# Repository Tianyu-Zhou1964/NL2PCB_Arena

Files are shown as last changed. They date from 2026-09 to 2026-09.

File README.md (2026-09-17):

# NL2PCB-Arena

让任意"基模 + harness"组合在同一个考场做 NL2PCB-Bench 的题，并把结果按统一口径汇总。
考场、agent 适配、轨迹、并发由 [Harbor](https://github.com/harbor-framework/harbor) 提供；本仓库只做三件事：

1. **题包**：`dataset/<task>/` 是一个 Harbor 任务。评测侧的 `bench/`（NL2PCB-Bench 任务目录：完整 `config.toml`、`cases/`）只进 verifier 镜像；发给 agent 的 `environment/`（题面、元件、工艺、骨架、公开自检配置）由 `nl2pcb-arena export` 生成。
2. **判卷**：`verifier/grader.py` 在独立、断网的 verifier 容器里跑完整的 `nl2pcb check`，写 `reward.json`（0/1）与 `grading.json`（逐规则状态、四类结果状态）。
3. **汇总**：`nl2pcb-arena report` 把 Harbor 的 job 结果按 任务 × harness × 模型 汇总成 pass@1、pass^k、规则级通过率、成本与轮数；基础设施故障不进能力分母。

## 快速开始（服务器，Docker 可用）

```sh
uv tool install harbor                                   # 0.23
scripts/sync_vendor.sh ../NL2PCB-Bench ../pcblite        # 依赖快照 + commit 记录
BASE_IMAGE=docker.m.daocloud.io/library/ubuntu:24.04 APT_MIRROR=mirrors.tuna.tsinghua.edu.cn \
    images/build.sh dev                                  # agent 镜像 → 导出题包 → verifier 镜像
scripts/server/prepare_harbor_sidecar.sh                 # 拉不到 Docker Hub 的机器：预构建 Harbor 的断网 sidecar
harbor run -p dataset/mini-led -a oracle                 # 参考答案应得 reward 1
harbor run -p dataset/mini-led -a nop                    # 什么都不做应得 0
harbor run -p dataset -a claude-code -m anthropic/claude-sonnet-5 -k 3 -n 4   # 真跑（花钱）
uv run nl2pcb-arena report jobs/<job>                    # 汇总
harbor add dataset/<新题> --to dataset && (cd dataset && harbor sync)   # 新题入清单、刷新 digest
```

## 考场里有什么

`kicad-cli`（KiCad 10.0.6，PPA 锁版）、`python3` + `pcbnew`、`ngspice`、`pcblite`（查询/编辑 `.kicad_pcb` 的命令行）、`nl2pcb check /task /workspace/answer.kicad_pcb`（公开规则自检）。没有 KiCad 标准库，封装只来自题包。agent 阶段可联网（模型端点需要），verifier 阶段断网。

## 题目

| 任务 | 层 | 起手板 | 公开规则 | 隐藏规则 |
|---|---|---|---|---|
| `mini-led` | L4 整板 | 骨架 | `pcb.drc`、`layout.fixed` | `electrical.led.current` |
| `mini-led-select` | L1 选型 | 骨架 | `layout.fixed`（`pcb.drc` 关：不要求布线） | `electrical.led.current` |
| `mini-led-repair-open` | L3 修复 | 开路板（缺一段走线，公开 DRC 报未连接） | `pcb.drc`、`layout.fixed` | `electrical.led.current` |
| `mini-led-repair-overcurrent` | L3 复核 | 47 Ω 板（DRC 干净，LED 约 62 mA） | `pcb.drc`、`layout.fixed` | `electrical.led.current` |

**通过不代表什么**（每题 `task.toml` 的 `not_implied` 也写了）：
L1 选型通过不代表会布线；L3 修复通过不代表能从零设计；L4 整板通过不代表可量产、可靠、EMC 合规；所有题的通过都只针对已配置的规则，不覆盖题面里没有对应规则的要求（工艺、焊接方式），也不代表真实焊接点亮过。

## 结果状态

| 状态 | 判定 |
|---|---|
| `passed` | 完整规则全部通过（`nl2pcb check` 退出 0） |
| `capability_failed` | 其余：答案缺失、解析失败、任一规则 fail/inconclusive |
| `agent_reported_blocker` | agent 写了 `/workspace/BLOCKER.md` |
| `infrastructure_failure` | 评分器自身失败（配置错误、超时、参考板也无法检查）、Harbor 报环境/agent 安装异常 |

`grading.json` 的 `network.isolated` 记录判卷容器是否真的断网（Harbor 的出口控制在内核探针失败时会静默关闭）；汇总报表会把 `false` 的 trial 单列出来。

`official_score_available = false`：本地 Docker 运行、agent 可联网、未经第三方盲测。正式对比要固定镜像 digest、题包 digest（`dataset.toml`）、Harbor 版本、重复次数与网络策略。

## 目录

```
dataset/<task>/          Harbor 任务：task.toml、instruction.md、bench/（评测侧）、environment/（生成）、solution/
images/agent/Dockerfile  共享 agent 镜像
images/verifier.Dockerfile  FROM agent + grader + dataset/*/bench
verifier/grader.py       判卷
src/nl2pcb_arena/        export（题包导出）、report（汇总）
vendor/                  NL2PCB-Bench、pcblite 快照（不提交，VERSIONS.json 记 commit）
docs/PLAN.md             方案与计划书
```

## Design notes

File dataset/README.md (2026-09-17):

# nl2pcb/nl2pcb-arena

Harbor 数据集清单 `dataset.toml` 由 `harbor dataset init` 生成，新题用 `harbor add dataset/<id> --to dataset` 加入，`harbor sync` 刷新 digest；每个子目录是一道 Harbor 任务。
题目形态、公开/隐藏规则与"通过不代表什么"见仓库根 `README.md` 与 `docs/PLAN.md`。

| 任务 | 层 | 起手板 | 公开规则 | 隐藏规则 |
|---|---|---|---|---|
| `mini-led` | L4 整板 | 骨架 | `pcb.drc`、`layout.fixed` | `electrical.led.current` |
| `mini-led-select` | L1 选型 | 骨架 | `layout.fixed`（`pcb.drc` 关：不要求布线） | `electrical.led.current` |
| `mini-led-repair-open` | L3 修复 | 开路板（缺一段走线） | `pcb.drc`、`layout.fixed` | `electrical.led.current` |
| `mini-led-repair-overcurrent` | L3 复核 | 47 Ω 板（DRC 干净但 LED 约 62 mA） | `pcb.drc`、`layout.fixed` | `electrical.led.current` |

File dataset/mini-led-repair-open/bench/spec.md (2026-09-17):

# 电源指示板（修复）

**目标**：从零设计一块用于普通桌面设备的5V单路LED电源指示PCB小板。

**功能**：+5 V （允许4.75–5.25V，外部电源限流20mA）经 2 脚连接器 J1 进板（1 脚正、2 脚回流），点亮一颗指示灯 D2。

**机械规格**：板框与 J1 的位置、方向已在 `assets/skeleton.kicad_pcb` 固定，不得修改。

**制造规格**：嘉立创普通 FR4 双层板、1 oz 外层铜、绿色阻焊、无铅喷锡、铣边，参数见 `assets/process/jlc_fr4_2l_1oz.toml`。贴片元件回流焊，J1 手焊。

**元件**：只能从 `assets/parts/` 选，清单见 `assets/parts/list.md`。位号 J1、D2 固定，其余自定。footprint 的 `Value` 写清单里的元件 id。

| 位号 | 元件 id | 说明 |
|---|---|---|
| J1 | `conn_2p_2mm` | 电源输入，1 脚 +5 V，2 脚回流 |
| D2 | `led_0805_red` | 指示灯 |

**起手板**：`answer.kicad_pcb` 的初始内容是一块已有的设计，它没有通过公开自检。请找出问题并修复后交付，改动尽量小；板框与 J1 不得修改。

**输出**：输出 `answer.kicad_pcb`，格式见 `assets/mini_kicad.md`。

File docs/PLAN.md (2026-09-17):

# NL2PCB-Arena 方案与计划书

2026-09-17 定稿（同日两版：先按自写 runner 写了一版；看过 Harbor 与 EDA-bench 后改为本版）。开发机：`zhou` 服务器 `~/zhoutianyu/NL2PCB-Arena`。

## 0. 一句话

NL2PCB-Bench 回答"这块板对不对"；NL2PCB-Arena 让任意 **基模 + harness** 组合在同一个考场做同一批题，并按统一口径汇总。Arena **不写 runner、不写 agent**：考场（Docker）、agent 适配（Claude Code / Codex / terminus-2 等 40 多个）、ATIF 轨迹、token 与成本记账、并发、重试、独立 verifier 环境全部由 [Harbor](https://github.com/harbor-framework/harbor)（Terminal-Bench 2.0 的官方 harness，0.23）提供。Arena 只做三件事：**题包、判卷、汇总**。同物种的 EDA-bench 就是这样建在 Harbor 上的，我们的结果口径可以和它直接对照。

## 1. 已定决策

| 编号 | 决策 | 结论 |
|---|---|---|
| D1 工具 | 考场提供什么 | 只提供命令行：`kicad-cli`、`pcblite`、公开版 `nl2pcb check`、`python3`（含 pcbnew）、`ngspice`。只要 harness 能执行 shell 就能参赛 |
| D2 自测 | agent 能否自测 | 能。容器内 `nl2pcb check /task /workspace/answer.kicad_pcb` 只跑**公开规则**；评分跑**全部规则**（含隐藏） |
| D3 隔离 | 隔离到什么程度 | Docker。评测侧文件只进 verifier 镜像；Harbor `environment_mode = "separate"` 在**全新、断网**的 verifier 容器里判卷，只有 `artifacts` 声明的 `/workspace` 被搬过去 |
| D4 框架 | 自写 runner 还是用现成 | **用 Harbor**。Arena 仓库 = 一个 Harbor 数据集 + 两个镜像 + 判卷脚本 + 汇总工具 |
| D5 仓库 | 代码放哪 | 新仓库 `NL2PCB-Arena`。Bench 与 pcblite 作为版本锁定的依赖（`scripts/sync_vendor.sh` 复制快照，commit 记进 `vendor/VERSIONS.json`），不改它们的代码 |
| D6 开发机 | 在哪开发 | `zhou`（Ubuntu 22.04 x86_64，256 核 / 377G / 1.5T 空闲 / Docker 28.3 + Compose v2.38）。本机只保留临时编辑镜像并 rsync |

## 2. 调查结论（事实，带出处）

### 2.1 NL2PCB-Bench（判卷器）

- 唯一入口 `nl2pcb check <task_dir> <answer.kicad_pcb> [--json]`，退出码 0 通过 / 1 有 error 级未通过 / 2 配置不合法 / 101 工具崩溃（`src/nl2pcb/cli.py:1-7`）。`--json` 每条 `diagnostic`、`report` 一行，末行 `run`。
- 任务目录可在仓库外；配置里**没有"公开/隐藏规则"概念**，规则调用的键按函数签名严格校验（`check/calls.py:130`）。公开/隐藏由 Arena 派生两份 config。
- 三条后端路径都要进容器：`kicad-cli`、KiCad 的 pcbnew Python（版本须 `10.0.*`，`worker.py:28`）、`ngspice`。
- 退出 101 不一定是环境坏了：损坏的答案文件也会让 `kicad-cli pcb export pos` 非零退出、`layout.fixed` 报 `crashed`。判卷时要拿参考板复核一次再定性（§5）。
- `spec/mini_kicad.md` 仍是占位，`lang/` 未写；题面改为"输出 KiCad 10 原生 `.kicad_pcb`"。

### 2.2 pcblite（agent 的改板工具）

- 用**本体仓库**（`Tianyu-Zhou1964/pcblite`，HEAD `feefd87`）的 `pcblite/` 包：纯标准库、11 个 .py、不 import pcbnew；`kicad-cli` 只在 `--refill`/`--check`/`verify`/老文件升级时用。没有 pyproject，容器里包一层 `/usr/local/bin/pcblite`。
- 31 个子命令：`open/export`、10 个查询、18 个编辑操作、`apply` 批量原子。编辑失败退出码 2 且不落盘。
- 交接包里的 9 个 JSON 工具是"从空板建板"协议（`agent_state.design()` 对存量板抛 `ARCHIVE_NOT_ALLOWED`，且依赖 pcbnew），**不采用**。
- **待验证风险**：`open → export → nl2pcb check` 在 09-14 跑通过，但早于 Bench 合入"封装库一致性 DRC"（PR #13）。verifier 镜像构建自检只验参考板；pcblite 往返要单独测（§8 P3）。

### 2.3 Harbor（考场与 runner）

- 任务 = 目录：`task.toml`（`schema_version = "1.4"`）+ `instruction.md` + `environment/`（agent 镜像构建上下文）+ `solution/solve.sh`（oracle）+ 可选 `tests/`。`harbor run -p <目录>` 直接跑本地任务或任务集合，无需发布。
- **separate verifier**：`[verifier] environment_mode = "separate"` + `[verifier.environment] docker_image = ...`；Harbor 先停 agent 容器，把 `artifacts` 声明的路径搬进新容器（原路径还原），`/logs/verifier` 先清空再跑 `/tests/test.sh`。**`tests/` 目录在 separate 模式下永不上传**，`test.sh` 必须烘进 verifier 镜像（`trial.py:894` `skip_tests_upload=True`）。
- reward：`/logs/verifier/reward.json`（优先）或 `reward.txt`。**pass@k 只在 reward 恰好一个键且值 ∈ {0,1} 时计算**（`utils/pass_at_k.py:44-51`）。
- agent 超时（`AgentTimeoutError`）或非零退出**不会跳过验证**：超时那一刻的工作区照常评分（`single_step.py:75-87`）；环境起不来 / agent 装不上则没有 `verifier_result`。
- 每个 trial 都在容器里装一次 agent CLI（claude-code 走 `bootstrap.sh`，codex 走 nvm + npm），默认安装超时 360 s；但 `install()` 看到 `command -v claude/codex` 成功就跳过 → **agent 镜像预装 node 22 + 两个 CLI**。
- claude-code 以 root 跑时 Harbor 自动 `IS_SANDBOX=1` + `--permission-mode=bypassPermissions`；`[agent].user` 可指定非 root。
- 模型与端点：claude-code 用 `-m <model>` + `--ae ANTHROPIC_API_KEY/ANTHROPIC_BASE_URL`（有自定义端点时模型名原样透传）；codex 用 `-m <model>` + `--ae OPENAI_API_KEY/OPENAI_BASE_URL`（Harbor 写进 `config.toml` 的 `openai_base_url`）；terminus-2（Harbor 自带的最薄 agent，LiteLLM）用 `-m openai/<model> --ak api_base=...`，密钥从**运行 harbor 的宿主环境**读。
- 产物：`jobs/<job>/<trial>/{result.json, agent/trajectory.json, agent/<原生日志>, verifier/{reward.json,test-stdout.txt,…}, artifacts/<声明路径>}`。`result.json` 有 `agent_info{name,version,model_info}`、`agent_result{n_input_tokens,n_cache_tokens,n_output_tokens,cost_usd}`、`verifier_result.rewards`、`exception_info.exception_type`、各阶段计时。内置统计给 mean reward 与 pass@k。
- 网络：`no-network` 不是 `--network none`，而是让容器共用一个 egress sidecar（基础镜像 `gogost/gost`，按内容哈希命名为 `harbor-prebuilt:harbor-docker-egress-control-sidecar--<hash>`）的网络命名空间，由它做 nftables 拦截。Harbor 会先跑 `alpine:3.23.4` 探针测内核，探针失败就**静默降级为 public**；sidecar 基础镜像要从 Docker Hub 拉，拉不到则整个 verifier 阶段报 `RuntimeError`（zhou 上已遇到：两个镜像站都不提供 gost）。对策：`scripts/server/prepare_harbor_sidecar.sh` 用 Harbor 自己的哈希算法算出镜像名、从可用镜像站按同一 digest 拉 gost 后预构建同名镜像（Harbor 见本地已有即复用）；`grader.py` 在判卷容器里实测 DNS 与 HTTP 出网（断网是透明代理，TCP 握手总成功，必须到应用层）并写进 `grading.json.network`，汇总报表把 `isolated=false` 的 trial 单列。
- 陷阱：`harbor run -o` 是 `--jobs-dir`；`-a terminus`/`terminus-1` 不可用，只有 `terminus-2`；多维 reward 文件名是 `reward.json`（模板注释里的 `rewards.json` 是错的）。

### 2.4 EDA-bench（同物种模板）

- 35 个真实开源硬件的重建任务，Harbor 0.19；**一个共享 agent 镜像 + 一个 `FROM agent` 的 verifier 镜像**，verifier 镜像里烘焙 gold、契约、评分代码与 `/tests/test.sh`，任务靠 `[verifier].env` 的 `EDA_BENCH_TASK_ID` 选择；agent 镜像构建上下文只有一个 Dockerfile 目录，物理上放不进 gold。
- `artifacts = ["/workspace/final_project"]` 单向搬运；verifier `no-network`；`grader.py` 写 `reward.json`（数值）+ `grading.json`（全部）+ `work/`。
- 值得抄：verifier `FROM` agent 保证判卷与自检用同一套二进制；相对 gold 的 DRC/ERC 打分吸收 KiCad 版本噪声；诊断项权重 0；DATA_CARD 里逐条写"高分不代表什么"。
- 不抄：全程 root、无 locale、不钉 KiCad 版本、可变镜像 tag、`metric.py` 按位置绑难度、agent 阶段开公网且 gold 公开可搜（他们自己承认）。

### 2.5 容器与服务器

- KiCad 官方镜像 `kicad/kicad:10.0` 只有 amd64；PPA `ppa:kicad/kicad-10.0-releases` 对 Ubuntu 24.04 有 amd64 与 arm64 的 `10.0.6~ubuntu24.04.1`。选 **`ubuntu:24.04` + PPA 锁版**，探针镜像已在服务器构建通过（kicad-cli 10.0.6、pcbnew 10.0.6、ngspice 42、Python 3.12.3，1.1 GB，3 分钟）。
- 服务器网络：Docker Hub 直连超时，`docker.m.daocloud.io` 可用；Ubuntu 源用清华 **http** 镜像（装 ca-certificates 前 https 不可用，已踩坑）；PPA、npm、nodejs.org 可达；GitHub 慢（构建期不 clone，改本地拷贝）；pypi 走清华。
- 本机 Mac 不用于开发：colima VM 已删；`brew` 装的 `colima`、`docker` 两个小包保留，可 `brew uninstall colima docker`。

### 2.6 从 Aspen-Agent 借的机制（只借机制）

| 借 | 落在哪 |
|---|---|
| 评分器只吃一个目录、可离线重跑、全部重算 | `harbor job regrade` + `verifier/grader.py`（separate 模式支持不重跑 agent 只重评） |
| 缺测量 = 失败，绝不视作 0 | 答案缺失/解析失败 = `capability_failed`；评分器崩溃 = `infrastructure_failure`；reward.json 一定落盘 |
| 状态分类，infra 优先级最高、不进能力分母；双分母 | `grading.json.status` + `nl2pcb-arena report`：`planned / scored / passed`，infra 与 not_run 单列 |
| `run_identity` 冻结身份 | Harbor 的 `result.json`（agent 名/版本/模型）+ 镜像内 `/opt/VERSIONS.json`（Bench、pcblite commit）+ `dataset.toml` 的任务 digest + `grading.json.tool_versions` |
| 每层"通过不代表什么" | `task.toml.[metadata].not_implied`，进 README 与 `grading.json` |
| agent 主动报阻塞是一等状态 | 题面约定 `/workspace/BLOCKER.md` → `agent_reported_blocker` |
| 每轮自检留痕 | 容器内 `nl2pcb` 包装脚本记 `/workspace/.arena/verifier_calls.jsonl`，grader 计数；评分不依赖它 |
| 污染审计 | verifier 镜像构建自检 + `tests/test_contamination.py`（agent 镜像里找不到 `cases/`、完整 config、参考板） |

**不借**：评测器往 agent 会话里注入追问、领域教学提示词、AST 白名单沙箱、按参考答案逐值匹配、无预算运行、人工科学评审悬置态、把 L 编号绑进 agent 工作流。

## 3. 评测口径

- **被测对象** = `(harness, model)`；harness 版本由 Harbor 记进 `agent_info.version`。
- **一次 trial** = 一题 × 一个组合 × 一次尝试（`-k` 重复）。
- **状态**（`grading.json.status`，顺序覆盖）：
  1. `passed`：完整规则全部通过（`nl2pcb check` 退出 0）。
  2. `capability_failed`：其余——答案缺失、解析失败、任一 error 级规则 fail / inconclusive、超时时的板子不合格。
  3. `agent_reported_blocker`：`/workspace/BLOCKER.md` 存在。
  4. `infrastructure_failure`：配置不合法（退出 2）、评分超时、工具崩溃且**参考板同样崩溃**；汇总时再并入 Harbor 的环境/安装/端点异常（`AgentAuthenticationError`、`ApiRateLimitError`、`EnvironmentStartTimeoutError`…）。
  5. `not_run`：Harbor 取消。
- **预算命中**单独记：agent 超时 → `budget_hit = "wall_time"`，状态仍由评分决定；`max_turns`/`max_budget_usd` 走各 harness 的 `--ak`。
- **reward**：`{"reward": 0|1}` 单键（保住 Harbor 的 pass@k）；规则通过比例、公开/隐藏是否通过在 `grading.json.scores`。
- **汇总**（`nl2pcb-arena report`，每 `(task, harness, model)`）：`n`、`scored`、`passed`、`pass@1`、`pass^n`、Wilson 95% 区间、逐规则通过率、成本/token/墙钟/轮数/自检次数中位数、infra 与 blocker 计数。交接包实测同配置 token 波动 ±30%，**每格至少 3 次**。
- **通过不代表什么**：L1 选型 ≠ 会布线；L3 修复 ≠ 能从零设计；L4 整板 ≠ 可量产/可靠/EMC；全部 ≠ 真实焊接点亮过，≠ 题面里没有规则的要求（工艺、焊接方式）。`official_score_available = false`：本地 Docker、agent 可联网、未经盲测。

## 4. 仓库与题目形态

```
NL2PCB-Arena/
  README.md  AGENTS.md  docs/PLAN.md  pyproject.toml  .gitignore  .dockerignore（白名单）
  images/agent/Dockerfile        共享 agent 镜像：ubuntu:24.04 + KiCad 10.0.6(PPA) + ngspice + node 22 + claude-code + codex
                                 + pcblite(/opt/pcblite) + nl2pcb(/opt/nl2pcb-bench，公开自检) + 用户 agent(uid 1000)
  images/agent/bin/{pcblite,nl2pcb}  命令包装；nl2pcb 顺手记自检日志
  images/verifier.Dockerfile     FROM agent + /tests/{grader.py,test.sh} + /opt/nl2pcb-arena/dataset（含隐藏 bench/）；构建时自检
  images/build.sh  images/export.sh   agent 镜像 → 在镜像里导出题包 → verifier 镜像
  verifier/grader.py  verifier/test.sh
  src/nl2pcb_arena/{export.py, report.py, cli.py}
  scripts/sync_vendor.sh         vendor/ 快照 + VERSIONS.json
  dataset/dataset.toml           Harbor 数据集清单：harbor dataset init 生成；新题 `harbor add dataset/<id> --to dataset`；`harbor sync` 刷新 digest
  dataset/<task>/
    task.toml                    Harbor 配置；[metadata] 放 tier / rules_public / rules_hidden / start_board / not_implied
    instruction.md               题面（唯一提示）：需求、环境里有什么、交付与 BLOCKER 约定；不含做法
    bench/                       评测侧：Bench 任务目录（config.toml、spec.md、cases/、assets/ 生成）
    start.kicad_pcb              可选：修复题的起手板
    environment/                 ← export 生成，提交进 git：Dockerfile（FROM agent 镜像 + COPY task /task + 起手板）、start.kicad_pcb、task/{spec.md, config.toml(公开), assets/}
    solution/solve.sh + solution/reference/answer.kicad_pcb   oracle
```

`task.toml` 的 Harbor 关键字段：顶层 `artifacts = ["/workspace"]`；`[verifier] environment_mode = "separate"`, `network_mode = "no-network"`, `env = { NL2PCB_TASK_ID = "<id>" }`, `timeout_sec = 900`；`[verifier.environment] docker_image = "nl2pcb-arena/verifier:<tag>"`；`[agent] timeout_sec = 1800`, `user = "agent"`；`[environment] network_mode = "public"`（模型端点要出网）, `workdir = "/workspace"`, `cpus = 4`, `memory_mb = 8192`。

公开 config 派生规则（`export.public_config`，纯函数，有单测）：去掉 `[[cases]]`；`[rules]` 只留 `rules_public` 点名的调用（按 `id` 或规则名）；默认开启但被列为隐藏的规则写 `level = "off"`；`task.reference` 改指 `assets/skeleton.kicad_pcb`。导出后用 Bench 自己的 `load_task + collect` 复核：公开 config 恰好只含公开规则，`public ∪ hidden` 等于 bench 启用的全部。

## 5. 判卷（`verifier/grader.py`）

在 verifier 容器里：读 `NL2PCB_TASK_ID` → `bench/` → 对 `/workspace/answer.kicad_pcb` 跑完整 `nl2pcb check --json`（600 s 超时）→ 写 `/logs/verifier/{reward.json, grading.json, work/}`。退出 101 时再对参考板跑一次：参考板过 → 崩溃是答案引起的（`capability_failed`）；参考板也崩 → `infrastructure_failure`。grader 自身异常也落盘并标 infra。`--selfcheck` 在构建 verifier 镜像时逐题验证：配置能加载、`public ∪ hidden` 覆盖全部规则、起手板/公开包/骨架存在、**参考板能通过完整检查**（每题可解）。

## 6. 运行

```sh
# 一次性
uv tool install harbor
scripts/sync_vendor.sh ../NL2PCB-Bench ../pcblite
BASE_IMAGE=docker.m.daocloud.io/library/ubuntu:24.04 APT_MIRROR=mirrors.tuna.tsinghua.edu.cn images/build.sh dev

# 自洽
harbor run -p dataset/mini-led -a oracle --job-name oracle     # reward 1
harbor run -p dataset/mini-led -a nop    --job-name nop        # reward 0

# 真跑（花钱）
export ANTHROPIC_API_KEY=...; harbor run -p dataset -a claude-code -m claude-sonnet-5 -k 3 -n 4 --ak max_turns=60 --ak max_budget_usd=5
export OPENAI_API_KEY=...;   harbor run -p dataset -a codex -m gpt-6-astra --ae OPENAI_BASE_URL=https://<中转>/v1 -k 3 -n 4
harbor run -p dataset -a terminus-2 -m openai/qwen3.7-plus --ak api_base=https://<端点>/v1 --ak max_turns=60 -k 3

# 汇总 / 查看 / 重评
uv run nl2pcb-arena report jobs/<job>
harbor view jobs
harbor job regrade jobs/<job> -p dataset/mini-led
```

## 7. 第一批题目

| id | 层 | 起手板 | 公开规则 | 隐藏规则 | 参考答案 | 通过不代表 |
|---|---|---|---|---|---|---|
| `mini-led` | L4 整板 | 骨架（板框 + J1） | `pcb.drc`、`layout.fixed` | `electrical.led.current` | Bench baseline（R1 = 5.1 kΩ，D2 ≈ 0.59 mA） | 可量产、可靠 |
| `mini-led-select` | L1 选型 | 骨架 | `layout.fixed`（`pcb.drc` 评测侧显式 off：不要求布线，公开版同样 off） | `electrical.led.current` | baseline | 会布线、铜线连通 |
| `mini-led-repair-open` | L3 修复 | `led-open-circuit`（R1.2–D2.2 缺一段线，公开 DRC 报未连接） | `pcb.drc`、`layout.fixed` | `electrical.led.current` | 用 pcblite `route` 补线并 `export --refill` 的板（`cases/led-open-repaired`，三条规则全过） | 从零设计 |
| `mini-led-repair-overcurrent` | L3 复核 | 47 Ω 板（baseline 改 R1；DRC 干净，D2 ≈ 62 mA > if_max 20 mA） | `pcb.drc`、`layout.fixed` | `electrical.led.current` | 330 Ω 板（≈ 9 mA） | 从零设计；分开"读题算电流"与"看报错改板" |

每题 `bench/` 是完整 Bench 任务目录，评分器不改。后三题共用 8 块案例板（Bench 的 5 块 + 47 Ω、330 Ω、修复板），标注 = 服务器上用完整配置实测的判定 + 物理推理，每条启用规则至少一正一反；`tests/test_grader_cases.py` 逐板核对判卷与标注一致。题面（`instruction.md`）只说范围与起手板来历，不点名隐藏规则：复核题只说"公开自检不覆盖全部要求，请按题面逐条核对"。

## 8. 提交计划（新仓库内原子提交；不推送）

| 步 | 内容 | 验证方式（不花 token） |
|---|---|---|
| P0 | 骨架：`pyproject`、`README`、`AGENTS.md`、`docs/PLAN.md`、`.gitignore`、`.dockerignore`、`scripts/sync_vendor.sh` | `uv sync`、`uv run nl2pcb-arena --help` |
| P1 | 题包导出：`export.py`（`public_config` 纯函数 + `export_task`）、`dataset/mini-led`（task.toml、instruction.md、bench/、solution/） | `pytest tests/test_export.py`；服务器 `images/export.sh` 生成 `environment/`，产物进 git |
| P2 | 镜像：`images/agent/Dockerfile`、`images/verifier.Dockerfile`、`images/build.sh`、`images/export.sh`、`verifier/{grader.py,test.sh}` | 服务器构建；verifier 自检通过；容器内 `claude --version`、`codex --version`、`pcblite --help`、`nl2pcb --help`；`tests/test_contamination.py` |
| P3 | 判卷链路：`harbor run -a oracle` → `passed`；`-a nop` → `capability_failed`；手工把 `j1-shifted` / 47 Ω 板 / `BLOCKER.md` 放进 workspace 走 `harbor job regrade` 或直接起 verifier 容器验证四类状态；**pcblite `open → export` 的板过完整 check** | 全在服务器 Docker 里，零 token |
| P4 | 汇总：`report.py`（状态映射、pass@1 / pass^n / Wilson、逐规则、成本）+ `dataset/dataset.toml`（`harbor sync`） | `pytest tests/test_report.py`（合成 trial 目录）；对 oracle/nop 的 job 出 `REPORT.md` |
| P5 | 分层题：`mini-led-select`、`mini-led-repair-open`、`mini-led-repair-overcurrent` | 每题 oracle 过、nop 不过；verifier 自检通过 |
| P6 | 真跑冒烟（**花钱，留给你触发**） | 先 `terminus-2` × 便宜模型 × `mini-led-select` × 1 次，看轨迹与报表；再上 claude-code / codex |

## 9. 风险与边界

- **pcblite 导出 vs 封装库一致性 DRC**：已实测通过——baseline `pcblite open → export --kicad 10` 往返板三条规则全过、`pcblite verify` 语义一致；修复题的参考答案就是 pcblite `route` + `export --refill` 出来的板。
- **鉴权**：服务器上跑 claude-code 需要 `ANTHROPIC_API_KEY` 或 `claude setup-token` 得到的 `CLAUDE_CODE_OAUTH_TOKEN`（本机订阅 OAuth 不能直接复制）；codex 用 `OPENAI_API_KEY` + `OPENAI_BASE_URL`；terminus-2 的密钥在宿主环境。密钥只从环境变量读，不进仓库、不进日志。
- **网络**：agent 阶段必须出网（模型端点），所以不能声称"agent 无法联网查资料"；报告注明。verifier 阶段 `no-network` 已实测（`grading.json.network`：DNS gaierror、HTTP 被 sidecar 直接断开，`isolated = true`）；每个 trial 都记录，报表把 `false` 的单列。zhou 上 Docker Hub 不通、两个镜像站不提供 `gogost/gost`，sidecar 由 `scripts/server/prepare_harbor_sidecar.sh` 从 `docker.1panel.live` 按同一 digest 预构建（见 2.3）。
- **隔离不是安全沙箱**：容器共享内核；`[agent].user = "agent"` + 只读 `/task` 只挡无意越权；agent 有 sudo。`official_score_available = false` 写进每份 `grading.json`。
- **题量与辨识度**：四道题都是"一电阻一 LED"，L4 会很快饱和；后续接 TPS5430 级别题（交接包有素材），并等 Bench 加放置/阻抗类规则。
- **随机性**：每格至少 3 次，报表始终带区间。
- **Harbor 版本**：0.23 的 `task.toml` schema 1.4；升级前跑 `harbor run --print-config` 与 oracle/nop 回归；升级后 sidecar 镜像名的内容哈希会变，要重跑 `scripts/server/prepare_harbor_sidecar.sh`。

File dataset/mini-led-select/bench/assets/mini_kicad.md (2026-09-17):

# mini_kicad 格式

将由 gendoc 生成

<!-- 占位。本文件作用：
     agent 提交的答案格式，kicad_pcb 的语法子集：只留设计决定，去掉生成物、样式、环境。
     骨架和 GT 也用它落盘；build_kit.py 把本文件原样拷进任务的 assets/ 发给 agent。

     内容：
     - 版本声明：generator 以 nl2pcb 开头时校验 generator_version
     - 节点表：footprint / pad / segment / via / zone / gr_rect|gr_poly|gr_line
     - 坐标与角度约定，pad 的 at 是未旋转偏移、rot 是绝对角
     - 网络靠名字不靠编号
     - 裁剪表：丢弃 / 拒绝两张名单
     - 常见错误 → parse.* 诊断码

     裁剪表的真相来源是 src/nl2pcb/lang/kicad.py 的 _*_DROP 集合，
     本文件对应小节由 dev/gen_mini_kicad_tables.py 生成，不手写维护两份。
     随 lang 层一起落地（PR #2）。
-->

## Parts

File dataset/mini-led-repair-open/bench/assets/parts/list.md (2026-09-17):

# 元件清单

footprint 的 Value 使用下表的元件 id。只能选择表内元件。
引脚号与名称见 symbols/ 中的对应符号，焊盘几何见 footprints/。

| id | 类别 | 描述 | 符号 | 封装 | 焊接 |
|---|---|---|---|---|---|
| [conn_2p_2mm](components/connector/conn_2p_2mm.toml) | connector | 2 位 2.00 mm 立式针座，通孔 | Connector_Generic:Conn_01x02 | Connector_TE-Connectivity:TE_440054-2_1x02_P2.00mm_Vertical | hand |
| [led_0805_red](components/led/led_0805_red.toml) | led | 红光 LED，0805，正向压降 2.0 V | Device:LED | LED_SMD:LED_0805_2012Metric | reflow |
| [res_0805_47](components/resistor/res_0805_47.toml) | resistor | 厚膜电阻 47Ω 0805 1/8 W | Device:R | Resistor_SMD:R_0805_2012Metric | reflow |
| [res_0805_100](components/resistor/res_0805_100.toml) | resistor | 厚膜电阻 100Ω 0805 1/8 W | Device:R | Resistor_SMD:R_0805_2012Metric | reflow |
| [res_0805_330](components/resistor/res_0805_330.toml) | resistor | 厚膜电阻 330Ω 0805 1/8 W | Device:R | Resistor_SMD:R_0805_2012Metric | reflow |
| [res_0805_1k](components/resistor/res_0805_1k.toml) | resistor | 厚膜电阻 1kΩ 0805 1/8 W | Device:R | Resistor_SMD:R_0805_2012Metric | reflow |
| [res_0805_5k1](components/resistor/res_0805_5k1.toml) | resistor | 厚膜电阻 5k1Ω 0805 1/8 W | Device:R | Resistor_SMD:R_0805_2012Metric | reflow |

## conn_2p_2mm

| 参数 | 值 |
|---|---|
| current_max_a | 3.0 |
| voltage_max_v | 250 |

## led_0805_red

| 参数 | 值 |
|---|---|
| color | red |
| if_max_a | 0.02 |
| vf_v | 2.0 |

## res_0805_47

| 参数 | 值 |
|---|---|
| power_w | 0.125 |
| resistance_ohm | 47 |
| tolerance | 0.005 |

## res_0805_100

| 参数 | 值 |
|---|---|
| power_w | 0.125 |
| resistance_ohm | 100 |
| tolerance | 0.005 |

## res_0805_330

| 参数 | 值 |
|---|---|
| power_w | 0.125 |
| resistance_ohm | 330 |
| tolerance | 0.01 |

## res_0805_1k

| 参数 | 值 |
|---|---|
| power_w | 0.125 |
| resistance_ohm | 1000 |
| tolerance | 0.01 |

## res_0805_5k1

| 参数 | 值 |
|---|---|
| power_w | 0.125 |
| resistance_ohm | 5100 |
| tolerance | 0.01 |

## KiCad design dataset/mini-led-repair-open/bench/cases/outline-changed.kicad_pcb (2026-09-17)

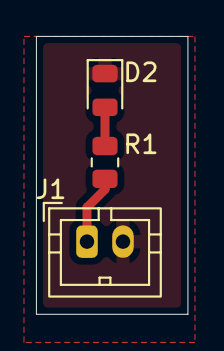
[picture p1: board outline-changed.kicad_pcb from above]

Board: 2 copper layers, 8.4 x 15.4 mm, 3 parts (0 on the bottom side), 3 nets.

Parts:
D2: led_0805_red; LED_0805_2012Metric
J1: conn_2p_2mm; TE_440054-2_1x02_P2.00mm_Vertical
R1: res_0805_5k1; R_0805_2012Metric

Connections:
+5V: J1.1, R1.1
GND: D2.1 (K), J1.2
unnamed: D2.2 (A), R1.2

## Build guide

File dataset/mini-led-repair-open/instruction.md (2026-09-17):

# 电源指示板（修复）

`/workspace/answer.kicad_pcb` 的初始内容是一块已有的设计（起手板），不是骨架。它没有通过公开自检。请找出问题并修复，改动尽量小，然后保存到同一路径；它是唯一会被评分的文件，格式是 KiCad 10 原生 `.kicad_pcb`。

## 需求

**目标**：从零设计一块用于普通桌面设备的 5 V 单路 LED 电源指示 PCB 小板。

**功能**：+5 V（允许 4.75–5.25 V，外部电源限流 20 mA）经 2 脚连接器 J1 进板（1 脚正、2 脚回流），点亮一颗指示灯 D2。

**机械规格**：板框与 J1 的位置、方向已在骨架中固定，不得修改。

**制造规格**：嘉立创普通 FR4 双层板、1 oz 外层铜、绿色阻焊、无铅喷锡、铣边，参数见 `/task/assets/process/jlc_fr4_2l_1oz.toml`。贴片元件回流焊，J1 手焊。

**元件**：只能从 `/task/assets/parts/` 选，清单见 `/task/assets/parts/list.md`。位号 J1、D2 固定，其余自定。footprint 的 `Value` 写清单里的元件 id。

| 位号 | 元件 id | 说明 |
|---|---|---|
| J1 | `conn_2p_2mm` | 电源输入，1 脚 +5 V，2 脚回流 |
| D2 | `led_0805_red` | 指示灯 |

## 环境

- `/task/spec.md`：本题面。`/task/assets/parts/`：允许使用的元件（符号、封装、参数）。`/task/assets/process/`：工艺参数。`/task/assets/skeleton.kicad_pcb`：骨架。`/task/assets/mini_kicad.md` 是占位文件，忽略它。
- 没有安装 KiCad 标准库，封装只能来自 `/task/assets/parts/footprints/`。
- 命令行工具：`kicad-cli`（KiCad 10.0.6，例如 `kicad-cli pcb drc`）、`python3`（可 `import pcbnew`）、`ngspice`、`pcblite`（查询和编辑 `.kicad_pcb` 的命令行，`pcblite --help`）。
- 自检：`nl2pcb check /task /workspace/answer.kicad_pcb` 用本题的公开规则检查答案；评分时还会运行题面要求但未公开的规则。

## 交付

- 把最终结果保存在 `/workspace/answer.kicad_pcb`。
- 如果确认任务无法完成，写 `/workspace/BLOCKER.md`，说明原因和缺少的信息。

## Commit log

2026-09-17 骨架：pyproject、README、AGENTS、计划书、忽略规则、vendor 快照脚本、CLI 入口
    - NL2PCB-Arena = 一个 Harbor 数据集 + 两个镜像 + 判卷脚本 + 汇总工具，不自写 runner/agent
    - vendor/ 只提交 VERSIONS.json（Bench 9cd9af3、pcblite feefd87），快照由 scripts/sync_vendor.sh 生成
    - docs/PLAN.md 记录决策、调查结论、评测口径与风险
2026-09-17 题包导出：export.py 与 mini-led（L4 整板）
    - public_config 纯函数：去 cases、只留公开规则、隐藏的默认规则显式 off、评测侧显式 off 的规则保持 off、reference 改指骨架
    - export_task 在 agent 镜像里用 Bench 的 build_assets 生成 bench/assets 与 environment/task；导出后用 Bench 的 load_task+collect 复核公开规则集合
    - dataset/mini-led：task.toml（[metadata] tier/rules_public/rules_hidden/not_implied）、题面、bench/（Bench 原任务目录）、solution/、生成的 environment/
    [alternative-layout.kicad_pcb, answer.kicad_pcb, baseline.kicad_pcb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]
2026-09-17 镜像与判卷：agent/verifier 镜像、构建脚本、grader、sidecar 预构建、污染审计
    - agent 镜像：ubuntu 24.04 + KiCad 10.0.6(PPA 锁版) + ngspice + node 22 + claude-code/codex 预装 + pcblite + 公开版 nl2pcb check + 用户 agent
    - verifier 镜像 FROM agent，烘进 /tests/grader.py 与 dataset/*/bench；构建时 --selfcheck 逐题验证参考板通过完整检查
    - grader 写 reward.json({reward:0|1}) 与 grading.json（四类 status、逐规则、network.isolated 断网实测）
    - scripts/server/prepare_harbor_sidecar.sh：Docker Hub 不通的机器上按 Harbor 的内容哈希预构建断网 sidecar
    - tests/test_contamination.py：考场镜像里不能有评测侧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
2026-09-17 判卷一致性测试：Bench 标注案例逐板核对，覆盖四类状态
    - 对每题 bench/config.toml 的 [[cases]] 逐板进判卷容器，pass/fail 标注必须与判卷一致
    - 参考板 passed、缺答案 capability_failed、BLOCKER.md → agent_reported_blocker；reward 单键契约
2026-09-17 汇总：report.py 与 Harbor 数据集清单
    - 读 Harbor job 目录，按 任务×harness×模型 出 pass@1、pass^k、Wilson 区间、逐规则通过率、成本/token/墙钟/轮数/自检次数
    - 基础设施故障与未运行不进分母；AgentTimeoutError 记 budget_hit 仍计分；判卷容器未断网的 trial 单列
    - dataset/dataset.toml 由 harbor dataset init/add/sync 维护
2026-09-17 分层题：mini-led-select（L1）、mini-led-repair-open（L3）、mini-led-repair-overcurrent（L3）
    - 选型题 pcb.drc 评测侧显式 off；修复题起手板为开路板；复核题起手板为 47 Ω 板（DRC 干净但 LED 约 62 mA）
    - 共用 8 块案例板（Bench 5 块 + 47 Ω、330 Ω、pcblite 补线的修复板），标注为实测判定 + 物理推理
    - 题面不点名隐藏规则；参考答案分别为 baseline、修复板、330 Ω 板
    [alternative-layout.kicad_pcb, answer.kicad_pcb, baseline.kicad_pcb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]
